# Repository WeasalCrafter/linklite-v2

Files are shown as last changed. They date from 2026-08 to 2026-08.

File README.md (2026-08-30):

<!-- PROJECT LOGO -->
<br />
<div align="center">
  <a href="https://github.com/weasalcrafter/linklite-v2">
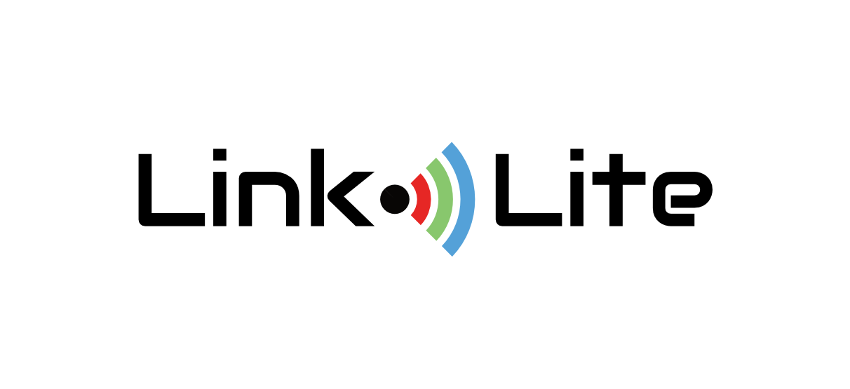
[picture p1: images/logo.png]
    
  </a>

  <h3 align="center">LinkLite v2</h3>

  <p align="center">
    A modular ESP32-C6 based room light that syncs brightness via ESP-NOW
    <br />
    <a href="https://www.loganfick.com/projects/linklite-v2">See my post on my Website</a><!--
    &middot;
    <a href="#">Project video on Youtube</a>-->
  </p>
</div>

<!-- TABLE OF CONTENTS -->
<details opeb>
  <summary>Table of Contents</summary>
  <ol>
    <li>
      <a href="#files">File Structure</a>
    <li><a href="#contact">Contact</a></li>
    <li><a href="#acknowledgments">Acknowledgments</a></li>
    <li><a href="#license">License</a></li>
  </ol>
</details>

<!-- ABOUT THE PROJECT -->
## About The Project

My dorm room lights are terrible in college, so I decided to make my own. LinkLite is the idea of a modular lighting system that lives locally and not in the cloud while allowing for wireless control and syncing. 

This is the second version of LinkLite, completely redesigned. This time with a custom PCB and much increased brightness.

### Built With

These are the major libraries I used in the programming in the project:

* RotaryEncoder
* Preferences
* ESP-NOW

<!-- CONTACT -->
## Files

The PCB project files can be found under ```kicad/linklite_v2```

```
linklite-v2
├── data
├── kicad
│   └── linklite_v2
├── linklite-bar
├── linklite-controller
├── temperature_logger
├── README.md
├── CLAUDE.md
└── LICENSE.txt
```

The arduino sketches for the ```linklite-bar```, ```linklite-controller```, and ```temperature_logger``` can be found under their respective folders, and my data collected can be found in the ```data``` folder along with the MATLAB script for plot generation.

<!-- CONTACT -->
## Contact

Logan Fick -  loganfickcontact@gmail.com

Project Link: [https://github.com/weasalcrafter/linklite-v2](https://github.com/weasalcrafter/linklite-v2)

Website: [https://loganfick.com/](https://loganfick.com/)

<!-- ACKNOWLEDGMENTS -->
## Acknowledgments
These are the tools I used for this project for designing the schematic, PCB layout, and programming.

* [Claude Code](https://www.claude.ai)
* [KiCad 10.0](https://www.kicad.org/)
* [Digikey Tools](https://www.digikey.com/en/resources/online-conversion-calculators)
* [MATLAB](https://www.mathworks.com/products/matlab.html)

## License

This project is licensed under the MIT License - see the [LICENSE](LICENSE.txt) file for details.

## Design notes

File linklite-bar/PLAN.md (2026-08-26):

# linklite-bar — Firmware Plan

Target: **ESP32-C6-MINI-1**, FQBN `esp32:esp32:esp32c6`. This is the authoritative brightness
node — see `CLAUDE.md` at the repo root for hardware pinout, the sync philosophy, and
conventions. This document is the detailed design for the `linklite-bar` sketch; the
accompanying `linklite-bar.ino` is a skeleton that implements the settled parts and stubs the
open ones with `// TODO(plan §n)` markers back into this file.

## 1. Responsibilities

The bar is the **stateful** half of the system (see CLAUDE.md "Sync model"). It:

1. Owns the authoritative brightness value for itself, and converges that value with peer bars.
2. Drives the LED array via LEDC PWM with a gamma-corrected curve.
3. Accepts brightness deltas and toggle events from controllers over ESP-NOW.
4. Answers late-joining bars' state queries so they converge instead of resetting the group.
5. Persists last brightness across power cycles.

Controllers never hold state — they only emit intent (`CLAUDE.md` §Sync model). Any logic that
looks like "wait for the controller to tell me the absolute level" is wrong; the bar decides.

## 2. Brightness domain

- Internal representation: **`uint8_t percent`, 0–100**, clamped on every mutation. Percent (not
  raw duty) is what gets stored in NVS, sent as `MSG_STATE`, and reasoned about in logic — it's
  radio- and hardware-independent.
- Conversion to PWM duty happens **only** at the output stage (§4), via a gamma LUT.
- One encoder detent from the controller = **±2 percent** (`STEP_SIZE_PERCENT`, shared constant
  with `linklite-controller`). Chosen so a full 0→100 sweep is ~50 detents — adjust after bench
  testing feels right; it's the one "magic number" both sketches must agree on today since there's
  no shared header between sketches yet (see §9 Conventions & gotchas).

## 3. GPIO & peripherals

Per `CLAUDE.md`:

| Function | GPIO | Mode |
|---|---|---|
| User button 1 | 20 | `INPUT_PULLUP`, debounced |
| User button 2 | 21 | `INPUT_PULLUP`, debounced |
| User LED | 22 | `OUTPUT` |
| Main LEDs | 23 | LEDC PWM (drives MOSFET gate)  |

## 4. LED driver (LEDC)

- **API:** arduino-esp32 3.x's pin-based LEDC calls — `ledcAttach(LED_PIN, freq, resBits)` /
  `ledcWrite(LED_PIN, duty)` — not the old channel-number API.
- **Frequency:** 5 kHz. Well clear of flicker/audible range, comfortably inside what the AO3400A
  can switch cleanly.
- **Resolution:** 12-bit (0–4095) for smooth low-end dimming.
- **Gamma correction:** the MOSFET+LED array is a linear-duty light source; human perception is
  roughly a power curve. Map `percent` (0–100) → duty via a **precomputed 101-entry LUT**
  (`const uint16_t GAMMA_LUT[101] PROGMEM`), `duty = round(4095 * (percent/100)^2.2)`.
  **Do not call `pow()`/float math at runtime on every step** — the C6 is RISC-V with no hardware
  FPU, so `pow()` is a soft-float library call; fine once at table-generation time (or precomputed
  by a script and pasted in as constants), not fine in a hot path.
- **At 0%:** drive duty to exactly 0, not the LUT's rounded near-zero value, so "off" is really off.

## 5. Boot sequence

1. Init serial (debug only), GPIO modes, LEDC attach.
2. Load persisted `percent` from NVS (`Preferences`, namespace `"linklite"`); if absent, default
   to a safe **25%** rather than 0% or 100% (visible but not startling). Drive the LEDC output to
   this provisional value immediately — don't leave the bar dark while radio comes up.
3. Bring up Wi-Fi STA (no AP association) pinned to the fixed **`WIFI_CHANNEL`** (both sketches
   hardcode the same channel — ESP-NOW requires it, and an unassociated STA otherwise reuses
   whatever channel is cached in Wi-Fi NVS, which can silently drift between devices). Init
   ESP-NOW, register the broadcast peer (`FF:FF:FF:FF:FF:FF`) and the recv callback.
4. Broadcast `MSG_QUERY`. Wait up to **500 ms** for `MSG_STATE` replies.
   - Every reply received in the window goes through the same last-write-wins comparison as
     steady-state heartbeats (§7.3): whichever `(level, stateVersion)` has the highest version
     wins, including possibly this bar's own NVS-loaded state if no peer beats it. This replaced
     an earlier "first reply wins" rule, which could stomp a correct persisted state with a
     lagging peer's stale reply.
   - If none arrive: this bar *is* the group (first one up, or alone) — keep the NVS/default value.
5. Enter main loop.

## 6. Main loop

Cooperative, non-blocking — no `delay()` in `loop()`:

- Poll button 1 / button 2 with debounce (simple time-based debounce is enough; these aren't
  latency-critical like the encoder).
- Drain a small ring buffer of received ESP-NOW packets (the recv callback runs in the Wi-Fi task
  context — keep it to "copy packet into buffer," do the real handling in `loop()`).
- Apply pending deltas → update `percent` → clamp 0–100 → `ledcWrite` via gamma LUT → mark NVS
  "dirty."
- Rate-limited NVS persistence: only write after **2 s of quiescence** since the last change, not
  on every step. Flash write cycles are finite and a fast encoder spin can generate many deltas/sec.
- Update the user LED per the status table in §8.
- Broadcast a `MSG_STATE` heartbeat every `STATE_HEARTBEAT_MS` (~100 ms) — the primary bar-to-bar
  sync mechanism, not just rare-drift reconciliation (§7.3); affordable because a converged bar's
  `peerStateWins()` check on receipt is cheap when `(version, level)` already match.

## 7. Wire protocol (ESP-NOW)

One packed struct, identical in both sketches until they're pulled into a shared header:

```c
typedef enum : uint8_t {
  MSG_DELTA  = 0x01,  // relative brightness step, from a controller (or another bar, unused today)
  MSG_TOGGLE = 0x02,  // on/off toggle, from a controller
  MSG_QUERY  = 0x03,  // "what's the current level?" — sent by a bar on boot
  MSG_STATE  = 0x04,  // response to MSG_QUERY, or periodic heartbeat (see §7.3)
} MsgType;

typedef struct __attribute__((packed)) {
  uint8_t  groupId;      // isolates separate physical installations sharing radio range; 0 = default
  uint8_t  msgType;      // MsgType
  uint8_t  senderType;   // 0 = bar, 1 = controller
  uint32_t seq;          // sender-local monotonic counter; debugging/ordering only, not for dedup
  int8_t   delta;        // MSG_DELTA/MSG_TOGGLE payload, in percent points
  uint8_t  level;        // MSG_STATE payload, absolute percent (0-100) — bootstrap/reconcile only
  uint32_t stateVersion; // MSG_STATE payload: Lamport-style logical clock, see §7.3
} LinkLitePacket; // 13 bytes
```

**Important distinction:** `level` in `MSG_STATE` is *not* a "set to X" control command — CLAUDE.md
is explicit that absolute set-points must never drive the control plane, because they let two
racing controllers stomp each other. `MSG_STATE` exists only to bootstrap a bar that has no local
state to converge from (§5 step 4) and, optionally, to nudge quiescent drift (§7.3). A bar must
never apply a received `MSG_STATE.level` while it has an active/recent delta stream in flight.

### 7.1 Delta application

On `MSG_DELTA`: `percent = clamp(percent + pkt.delta, 0, 100)`. On `MSG_TOGGLE`: if `percent > 0`,
remember it as `lastNonZeroPercent` and set `percent = 0`; if `percent == 0`, restore
`lastNonZeroPercent` (or the 25% default if none recorded yet).

### 7.2 No relay/rebroadcast in v1

Bars do **not** rebroadcast deltas they receive. ESP-NOW broadcast is single-hop and, for the
target install size (a handful of bars in one room, well within radio range of every controller
and each other), every bar hears every controller directly — a mesh relay adds storm-prevention
complexity (loop detection, TTLs, dedup) for no benefit at this scale. If a future install needs
bars spread across a range no single controller can reach, revisit this — it's a deliberate scope
cut, not an oversight.

### 7.3 Drift correction — last-write-wins via logical clock, implemented

Missed broadcasts (radio interference, a bar briefly out of range) cause silent drift between bars
since delta application isn't acknowledged — previously the only recovery was manually cranking
every bar to a rail (0% or 100%) so the independent-clamping property (§11) forced convergence.

**Design:** each bar keeps `brightnessVersion: uint32_t`, a Lamport-style logical clock (not
wall-clock time) tied 1:1 to its own `percent` mutations:

- **Local-origin mutation** (this bar applied a delta/toggle it received, or a local button press) →
  `version = version + 1`. This bar just created a new fact.
- **Remote-origin mutation** (adopting a peer's state) → `version = peerVersion`, assigned outright,
  *not* incremented. This bar isn't creating a new fact, it's aligning to one that already exists.
  Incrementing here too would make two bars that just converged each think they're now newest,
  oscillating forever instead of settling — this distinction is the crux of the whole scheme.
- Deliberately **not** persisted to NVS. Every reboot starts at `version = 0`, so a restarted bar
  has no standing in `peerStateWins()` and must join the group's current state via the boot query
  (§5 step 4) rather than asserting whatever it last knew — a bar that remembered its version
  across reboots could out-rank a peer's genuinely current state after a power cycle (e.g. mid
  firmware update) and stomp the group with a stale level. `percent` is still persisted, but only
  as a display fallback for the solo/no-peers case, not as a claim on the group's state.

Each bar broadcasts `MSG_STATE` (now carrying `level` **and** `stateVersion`) every
`STATE_HEARTBEAT_MS` (15 s). On receiving *any* `MSG_STATE` — heartbeat or boot-query reply, same
code path — a bar compares:

- `peerVersion > localVersion` → adopt the peer's `(level, version)`.
- `peerVersion == localVersion` but `level` differs → deterministic tie-break on MAC address
  (larger wins), so the group can't oscillate. This only arises from a genuinely concurrent or
  partitioned write (e.g. a bar toggled locally while out of range, whose increment from a stale
  baseline happens to numerically match a peer's independently-advanced version) — under normal
  operation, every mutation is broadcast and applied identically everywhere, so all bars advance
  their version in lockstep and this branch essentially never fires.
- `peerVersion < localVersion` → ignore; the peer is behind and will catch up on its next heartbeat.

This **replaced** the originally-proposed "nudge one step toward the received value if quiescent"
design. A bar only diverges when it's already missed updates — i.e. it's already visibly wrong —
so snapping straight to the winning value is the more direct fix, and the logical-clock ordering
already gives the "don't override a bar mid-adjustment" property the nudge/quiescence heuristic was
reaching for: a bar applying its own deltas keeps incrementing its own version, so a stale peer
heartbeat can't be `>` it and can't win.

Bench-validated behavior to confirm: induce packet loss on one bar mid-session, confirm it
re-converges within one heartbeat interval once back in range, and confirm no oscillation between
two bars deliberately desynced to the same version with different levels.

## 8. User LED (GPIO22) status codes

| State | Pattern |
|---|---|
| Normal / converged | Solid on |
| Booting, waiting for `MSG_STATE` | Slow blink (2 Hz) until step 5  |
| Delta received (activity indicator) | Brief single flash (~30 ms) |
| Pairing / group-assign mode (§9) | Fast blink (5 Hz) |
| Fault (e.g. ESP-NOW init failed) | Triple-flash, repeating |

## 9. Buttons 1 & 2 — OPEN DECISION, proposed defaults

CLAUDE.md doesn't define these; per the project's own convention of flagging rather than silently
deciding (see its Wireless transport section), here's a proposal to confirm, not a final answer:

- **Button 1, short press:** local on/off toggle — same effect as a controller `MSG_TOGGLE`,
  applied locally and then broadcast so peers follow. Useful for a bar with no controller nearby.
- **Button 1, long press (~2 s):** identify — fast-blink the user LED and pulse the main LEDs
  briefly, useful for figuring out which physical bar you're touching during setup.
- **Button 2:** reserved for **group/pairing management** (`groupId` assignment) — mechanism TBD.
  The simplest version: long-press enters pairing mode (fast user-LED blink), during which the bar
  accepts a `groupId` broadcast from a designated "pairing controller" gesture (e.g. a long
  controller-button-press while in range). This needs a controller-side counterpart that doesn't
  exist yet — out of scope until `linklite-controller`'s button role is revisited past its current
  on/off-toggle default (see repo root `CLAUDE.md`).

The skeleton wires both buttons with debounce and stubs their handlers; button 1's short-press
toggle is implemented (it's simple and low-risk), everything else is `// TODO(plan §9)`.

## 10. Persistence (NVS via `Preferences`)

Namespace `"linklite"`, keys: `pct` (`uint8_t`, last brightness — display fallback only, not a
state claim) and `grp` (`uint8_t`, `groupId`, default 0). `brightnessVersion` is intentionally
**not** persisted (see §7.3) so every boot re-joins the group via query instead of asserting a
possibly-stale version. Write path is rate-limited per §6. No encryption/auth on the ESP-NOW link
in v1 — flag
per CLAUDE.md's "don't silently pick" spirit: this means anything in radio range can inject deltas.
Acceptable for a single-room consumer light; revisit if the threat model changes (`esp_now` supports
per-peer AES-CCM encryption if needed later).

## 11. Edge cases

- **Two controllers turning at once:** deltas are commutative by construction (§7.1) — no special
  handling needed, this is the whole point of the delta model.
- **Clamping at rails:** every node clamps independently to 0–100; since clamping is deterministic
  and the same function everywhere, nodes can't drift apart at the rails even without coordination.
- **Late join:** handled by boot-time `MSG_QUERY`/`MSG_STATE` (§5). A bar joining mid-session must
  not default to a guessed value if peers are present.
- **Solo bar (no peers, no controller):** boots to NVS value or 25% default; buttons still work
  locally.
- **NVS write during brownout/power loss:** rate-limiting (§6) minimizes the window; worst case is
  losing up to 2 s of the most recent change, not corruption (`Preferences` commits are atomic per
  key).

## 12. File layout

- `linklite-bar.ino` — `setup()`/`loop()`, wires everything below together.
- `config.h` — pin defs, `LinkLitePacket`/`MsgType`, `WIFI_CHANNEL`, `STEP_SIZE_PERCENT`,
  `GAMMA_LUT`, timing constants. Kept as a header (not split .cpp/.h per module) since the sketch
  is still small; revisit if it grows past a few hundred lines per file.

## 13. Bench test plan (before calling this done)

1. Single bar, no controller: boots to default, buttons work, NVS persists across power cycle.
2. Single bar + single controller: rotate CW/CCW, confirm smooth gamma-correct dimming; push
   button toggles; confirm `STEP_SIZE_PERCENT` feels right, tune if not.
3. Two bars, one controller: both converge to the same brightness on every delta; power-cycle one
   bar mid-session and confirm it re-queries and converges instead of resetting.
4. Two bars, two controllers, simultaneous opposite turns: confirm net delta lands correctly with
   no fighting/flicker.
5. Induce packet loss (walk a bar out of range briefly): confirm behavior is "graceful drift," not
   a crash or LEDC glitch; use this to validate (or invalidate) §7.3 before implementing it.

## 14. Explicit open items (don't silently resolve — confirm first)

- §7.3 Drift-reconciliation heartbeat — implemented (last-write-wins via logical clock); not yet
  bench-validated against induced packet loss. `STATE_HEARTBEAT_MS` (~100 ms) chosen to make the
  heartbeat the primary sync path rather than a rare-case backstop; `RX_QUEUE_LEN` (linklite-bar.ino)
  was widened alongside it since the queue is shared with real controller commands.
- §9 Button roles — button 1 short-press implemented as proposed; everything else pending.
- §9 groupId assignment/pairing mechanism — no controller-side counterpart exists yet.
- `STEP_SIZE_PERCENT` (2%/detent) and the 25% power-on default — reasonable starting guesses, tune
  after bench testing.
- No ESP-NOW encryption — acceptable for now, flagged for revisit.

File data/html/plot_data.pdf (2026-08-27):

# Table of Contents

# --- Load Data ---

file = 'linklite_data_4.csv';
data = readmatrix(file); | % 20x9 numeric matrix
hdr = readcell(file, 'Range', '1:1'); | % header row (cell array of
strings)
brightness = 1; | % (%)
scaled_duty = 3; | % (%)
measured_duty = 4; | % (%)
total_current = 5; | % mA
power_consumption = 6; % W
voltage_drop = 7; | % V
voltage_rail = 8; | % V
led_current = 9; | % mA

efficiency = ((data(:,led_current) * 28) .* data(:,voltage_rail)) ./ ... ((data(:,total_current) - 72) * 15); % (%)

buck_output = efficiency .* data(:,total_current) .* 15 ./ data(:,voltage_rail)

buck_output =

1.0e+03 *

NaN
NaN
0.0818
0.1194
0.1494
0.1675
0.1875
0.2215
0.2546
0.2960
0.3427
0.3925
0.4502
0.5219
0.5954
0.6698
1.1706

1.3122
1.4525
1.5970
1.7941

# graphing data

figure;

sgtitle("Linklite Power Metrics", 'fontsize', 44);

subplot(2,2,1);
plot(data(:,brightness), data(:,power_consumption), '-c', 'LineWidth', 2.5, 'MarkerSize', 10, 'Color', 'g');
title("Power Consumption (W) vs. Brightness (%)", 'FontSize', 28)
xlim([0 100]);
grid on;

subplot(2,2,2);
plot(data(:,brightness), data(:,led_current), 'LineWidth', 2.5, 'Color', 'r'); xlim([0 100]);
ylim([0 60]);
title("LED Forward Current (V) vs. Bightness (%)", 'FontSize', 28);
grid on;

subplot(2,2,3);
plot(data(:,brightness), efficiency, 'LineWidth', 2.5, 'Color', 'y'); xlim([0 100]);
ylim([0 1]);
title("Calculated Buck Efficiency (%) vs. Brightness (%)", 'FontSize', 28); grid on;

subplot(2,2,4);
plot(data(:,brightness), buck_output, 'LineWidth', 2.5, 'color', 'c'); xlim([0 100]);
ylim([0 2000]);
title("Buck Output (mA) vs. Brightness (%)", 'FontSize', 28);
grid on;

for k = 1:4
subplot(2,2,k);
% ... your plot, title, labels ... set(gca, 'FontSize', 20);
end

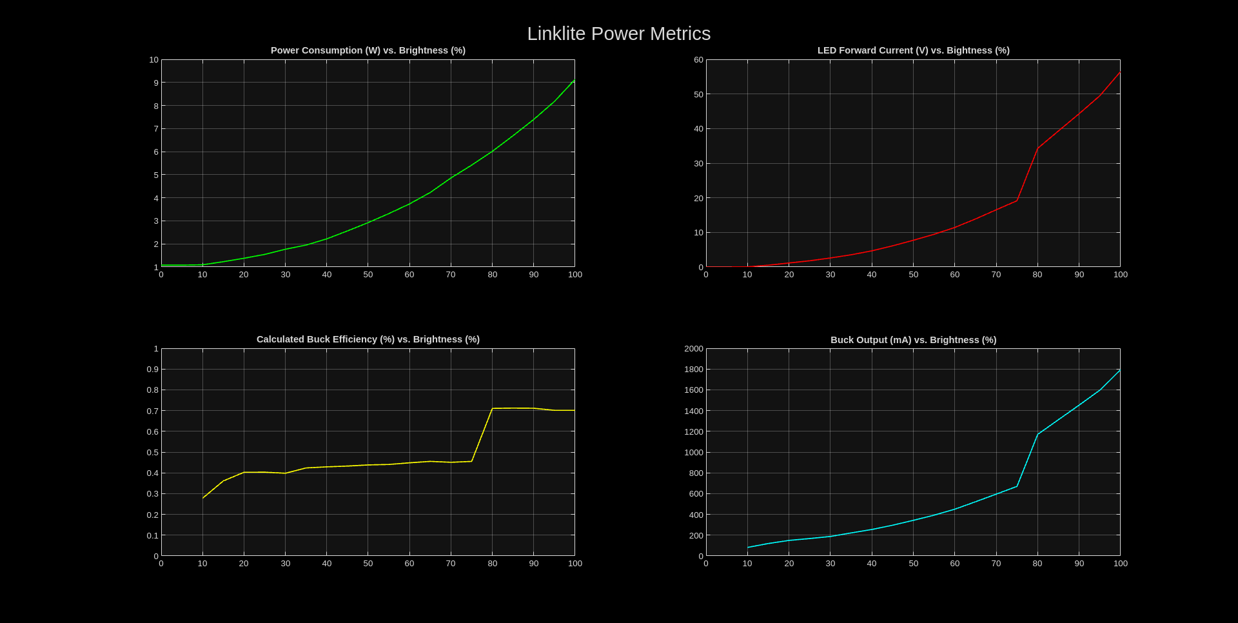
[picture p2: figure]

# --- Load and Graph Experimental Data ---

figure

hold on

temp_file = 'files/data_006.csv';
temp_data = readmatrix(temp_file); plot(temp_data(:,1),temp_data(:,2),'LineWidth',2);

temp_file = 'files/data_010.csv';
temp_data = readmatrix(temp_file); plot(temp_data(:,1),temp_data(:,2),'LineWidth',2);

temp_file = 'files/data_008.csv';
temp_data = readmatrix(temp_file); plot(temp_data(:,1),temp_data(:,2),'LineWidth',2);

temp_file = 'files/data_009.csv';
temp_data = readmatrix(temp_file); plot(temp_data(:,1),temp_data(:,2),'LineWidth',2);

temp_data_1 = readmatrix('files/data_011.csv'); temp_data_2 = readmatrix('files/data_012.csv');
temp_data_3 = readmatrix('files/data_013.csv');

% shortest row count across the three
n = min([size(temp_data_1,1), size(temp_data_2,1), size(temp_data_3,1)]);

% trim each to n rows
d1 = temp_data_1(1:n, :);
d2 = temp_data_2(1:n, :);

d3 = temp_data_3(1:n, :);

averaged_temp = (d1(:,1) + d2(:,1) + d3(:,1)) ./ 3; plot(averaged_temp, d1(:,2));

temp_file = 'files/data_014.csv';
temp_data = readmatrix(temp_file); plot(temp_data(:,1),temp_data(:,2),'LineWidth',2);

hold off
grid on

set(gca, 'FontSize', 24);

xticks(0:300:1800);
xlim([0 1800]);

yticks(20:5:70);
ylim([20 70]);

xlabel("Time (s)", FontSize=28);
ylabel("Temperature (C)", FontSize=28);
title("LED-Side PCB Temperature (Celsius) vs. Time (Seconds)",FontSize=38);

legend( ...
'Single 90% (014)', ...
'Single 80% (006)', ...
'Single 80% (010)', ...
'Double 80% (008)', ...
'Triple 80% (009)', ...
'Single 60% (011/012/013)', ... 'fontsize',28, ...
'Location','Southeast' ...
);

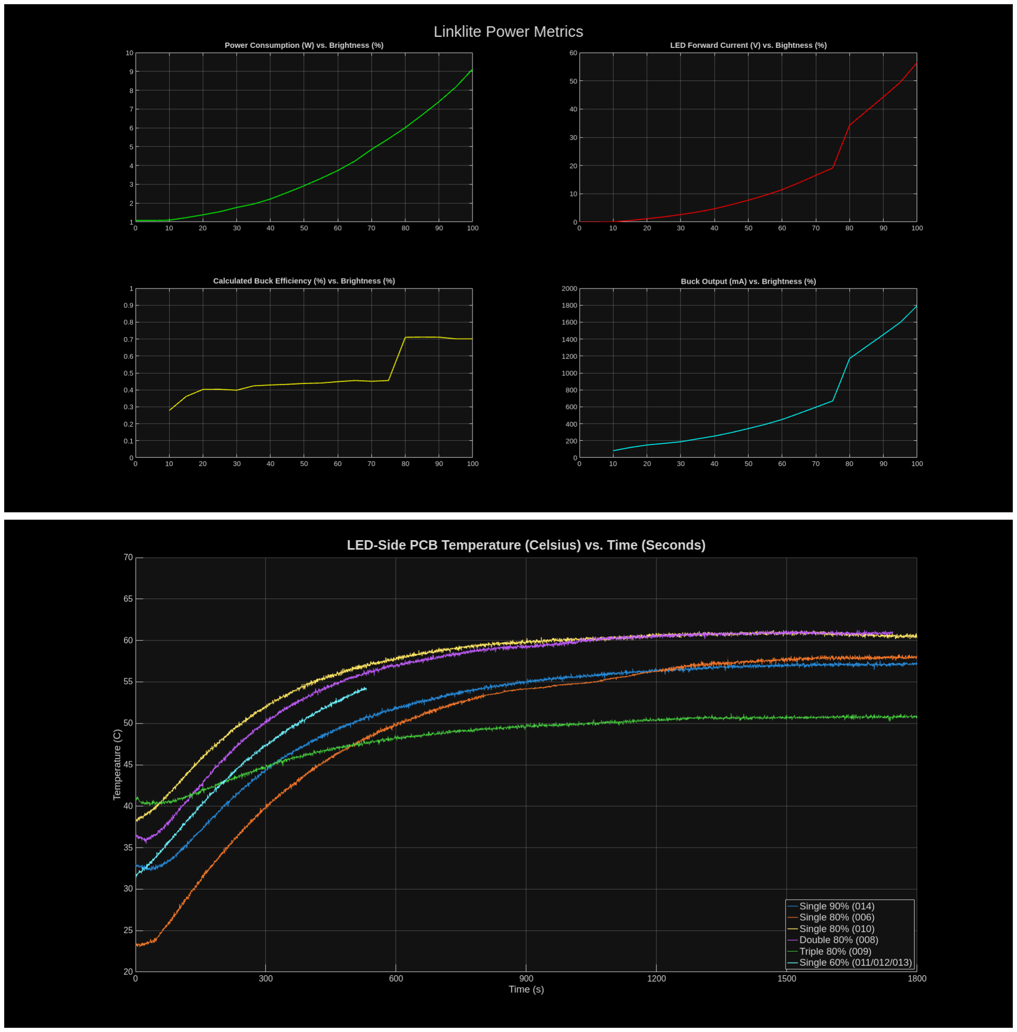
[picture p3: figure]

Published with MATLAB® R2025b

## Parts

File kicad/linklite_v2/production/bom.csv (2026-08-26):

Designator | Footprint | Quantity | Value | LCSC Part #
C1, C4, C5 | 0603 | 3 | 0.1uF
C10 | CAP-SMD_BD6.3-L6.6-W6.6-LS7.3-FD_JVS25V100M6X4 | 1 | JVS25V100M6X4 | C51953404
C13, C6 | 0805 | 2 | 22uF
C15, C16 | 0805 | 2 | 10uF 25V
C17 | 0603 | 1 | 0.1uF 25V
C2 | 0603 | 1 | 22uF
C3, C9 | 0603 | 2 | 1uF
C8 | 0805 | 1 | 0.1uF 25V
D3 | D_MiniMELF | 1 | BZV55B10
D4 | SMC_L7.1-W6.2-LS8.1-FD | 1 | SMCJ15A-13-F | C135138
F3, F4 | F2920 | 2 | JK-SMD300L-24V | C841188
J2 | PinHeader_1x03_P2.54mm_Horizontal | 1 | Conn_01x03_Pin
J3 | PinHeader_1x11_P2.54mm_Horizontal | 1 | Conn_01x11_Pin
L1 | IND-SMD_L7.3-W6.6 | 1 | MHCI06030-3R3M-R8 | C108294
LED1, LED10, LED11, LED12, LED13, LED14, LED15, LED16, LED17, LED18, LED19, LED2, LED21, LED22, LED23, LED25, LED26, LED27, LED29, LED3, LED30, LED31, LED4, LED5, LED6, LED7, LED8, LED9 | LED-SMD_L3.5-W2.8-FD-2835_WHITE | 28 | JTLMS3 | C34162565
LED33 | LED0603-RD_RED | 1 | PD LED RED | C94743
LED35 | LED0603-RD_RED | 1 | USR LED BLUE | C481916
LED36 | LED0603-RD_RED | 1 | PWR LED GREEN | C84267
Q2 | SOT-23-3_L2.9-W1.6-P1.90-LS2.8-BR | 1 | G7P03L | C840062
Q3 | SOT-23 | 1 | AO3400A
R1, R17, R19, R20, R21, R22, R23, R24, R25, R26, R27, R28, R29, R30, R31, R32, R33, R34, R36, R37, R38, R40, R41, R42, R44, R45, R46, R6 | 0603 | 28 | 5.6 | C325756
R10, R16, R2, R4, R48, R49, R7, R8, R9 | 0603 | 9 | 10K
R11 | 0603 | 1 | 33.2K
R12 | 0603 | 1 | 160
R13 | 0603 | 1 | 1K
R14, R15 | 0603 | 2 | 5.1K
R18, R5 | 0603 | 2 | 100K
R3 | 0603 | 1 | 220
R50 | 0603 | 1 | 180
R51 | 0603 | 1 | 130
SW3 | SW-SMD_4P-L3.5-W3.0-P1.50-LS4.7 | 1 | RESET | C51927445
SW4 | SW-SMD_4P-L3.5-W3.0-P1.50-LS4.7 | 1 | BOOT | C51927445
SW5, SW6 | SW-SMD_4P-L3.5-W3.0-P1.50-LS4.7 | 2 | USR 1 | C51927445
U2 | ESP32-C6-MINI-1 | 1 | ESP32-C6-MINI-1 | C5736265
U3 | SOT-666 | 1 | USBLC6-2P6
U5 | SOT-23-6 | 1 | CH221K
U6 | CONN-SMD_2060-452 | 1 | PWR OUT | C2765055
U7 | SOT-23-6_L2.9-W1.6-P0.95-LS2.8-BR | 1 | TPS563201DDCR | C116592
U8 | CONN-SMD_2060-452 | 1 | PWR IN | C2765055
USBC1 | USB-C_SMD-TYPE-C-31-M-12_1 | 1 | TYPE-C-31-M-12 | C165948

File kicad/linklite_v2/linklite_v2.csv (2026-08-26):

Designator | Comment | Footprint | LCSC Part
USBC1 | TYPE-C-31-M-12 | EasyEDA2KiCad:USB-C_SMD-TYPE-C-31-M-12_1 | C165948
U8 | PWR IN | EasyEDA2KiCad:CONN-SMD_2060-452 | C2765055
U7 | TPS563201DDCR | EasyEDA2KiCad:SOT-23-6_L2.9-W1.6-P0.95-LS2.8-BR | C116592
U6 | PWR OUT | EasyEDA2KiCad:CONN-SMD_2060-452 | C2765055
U5 | CH221K | Package_TO_SOT_SMD:SOT-23-6
U3 | USBLC6-2P6 | Package_TO_SOT_SMD:SOT-666
U2 | ESP32-C6-MINI-1 | RF_Module:ESP32-C6-MINI-1
SW5,SW6 | USR 1 | EasyEDA2KiCad:SW-SMD_4P-L3.5-W3.0-P1.50-LS4.7 | C51927445
SW4 | BOOT | EasyEDA2KiCad:SW-SMD_4P-L3.5-W3.0-P1.50-LS4.7 | C51927445
SW3 | RESET | EasyEDA2KiCad:SW-SMD_4P-L3.5-W3.0-P1.50-LS4.7 | C51927445
R14,R15 | 5.1K | Resistor_SMD:R_0603_1608Metric
R13 | 1K | Resistor_SMD:R_0603_1608Metric
R12,R50,R51 | 75 | Resistor_SMD:R_0603_1608Metric
R11 | 33.2K | Resistor_SMD:R_0603_1608Metric
R5,R18 | 100K | Resistor_SMD:R_0603_1608Metric
R4,R7,R8,R9,R10,R16,R48,R49 | 10K | Resistor_SMD:R_0603_1608Metric
R3 | 220 | Resistor_SMD:R_0603_1608Metric
R2 | 10k | Resistor_SMD:R_0603_1608Metric
R1,R6,R17,R19,R20,R21,R22,R23,R24,R25,R26,R27,R28,R29,R30,R31,R32,R33,R34,R36,R37,R38,R40,R41,R42,R44,R45,R46 | 5.8 | Resistor_SMD:R_0603_1608Metric
Q3 | AO3400A | Package_TO_SOT_SMD:SOT-23
Q2 | G7P03L | EasyEDA2KiCad:SOT-23-3_L2.9-W1.6-P1.90-LS2.8-BR | C840062
LED36 | PWR LED GREEN | EasyEDA2KiCad:LED0603-RD_RED | C94743
LED35 | USR LED BLUE | EasyEDA2KiCad:LED0603-RD_RED | C94743
LED33 | PD LED RED | EasyEDA2KiCad:LED0603-RD_RED | C94743
LED1,LED2,LED3,LED4,LED5,LED6,LED7,LED8,LED9,LED10,LED11,LED12,LED13,LED14,LED15,LED16,LED17,LED18,LED19,LED21,LED22,LED23,LED25,LED26,LED27,LED29,LED30,LED31 | JTLMS3 | EasyEDA2KiCad:LED-SMD_L3.5-W2.8-FD-2835_WHITE | C34162565
L1 | MHCI06030-3R3M-R8 | EasyEDA2KiCad:IND-SMD_L7.3-W6.6 | C108294
J3 | Conn_01x11_Pin | Connector_PinHeader_2.54mm:PinHeader_1x11_P2.54mm_Horizontal
J2 | Conn_01x03_Pin | Connector_PinHeader_2.54mm:PinHeader_1x03_P2.54mm_Horizontal
H1,H2,H3,H4 | MountingHole | MountingHole:MountingHole_3.2mm_M3_Pad_TopBottom
F3,F4 | JK-SMD300L-24V | EasyEDA2KiCad:F2920 | C841188
D4 | SMCJ15A-13-F | EasyEDA2KiCad:SMC_L7.1-W6.2-LS8.1-FD | C135138
D3 | BZV55B10 | Diode_SMD:D_MiniMELF
C17 | 0.1uF 25V | Capacitor_SMD:C_0603_1608Metric
C15,C16 | 10uF 25V | Capacitor_SMD:C_0805_2012Metric
C10 | JVS25V100M6X4 | EasyEDA2KiCad:CAP-SMD_BD6.3-L6.6-W6.6-LS7.3-FD_JVS25V100M6X4 | C51953404
C8 | 0.1uF 25V | Capacitor_SMD:C_0805_2012Metric
C6,C13 | 22uF | Capacitor_SMD:C_0805_2012Metric
C3,C9 | 1uF | Capacitor_SMD:C_0603_1608Metric
C2 | 22uF | Capacitor_SMD:C_0603_1608Metric
C1,C4,C5 | 0.1uF | Capacitor_SMD:C_0603_1608Metric

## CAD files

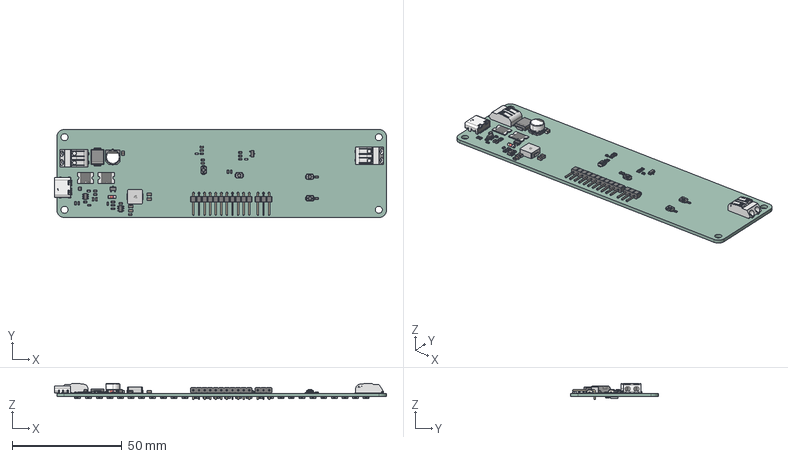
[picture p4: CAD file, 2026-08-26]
kicad/linklite_v2/.step
151.1 x 40.0 x 7.50 mm
C_0603_1608Metric x 7
C_0805_2012Metric x 5
R_0603_1608Metric x 47
KEY-SMD_2P-L3.0-W2.5-H1.6-LS4.0 x 4
PinHeader_1x03_P254mm_Horizontal
SOT-23-6_L2.9-W1.6-H1.5-LS2.8-P0.95
SOT_666
PinHeader_1x11_P254mm_Horizontal
LED0603-RD_RED x 3
IND-SMD_L7.1-W6.6-H2.8
D_MiniMELF_Standard
F2920-1 x 2
SOT-23-3L_L2.9-W1.6-H1.1-LS2.8-P0.95
SOT-23-6
CONN-SMD_2060-452 x 2
SOT-23
CAP-SMD_BD6.3-L6.6-W6.6-LS7.3-FD_JVS25V100M6X4
USB-C_SMD-TYPE-C-31-M-12
SMC_L7.1-W6.2-LS8.1-FD
LED-SMD_L3.5-W2.8-FD-2835_WHITE x 28
linklite_v2_PCB

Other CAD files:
kicad/linklite_v2/linklite-v2.step

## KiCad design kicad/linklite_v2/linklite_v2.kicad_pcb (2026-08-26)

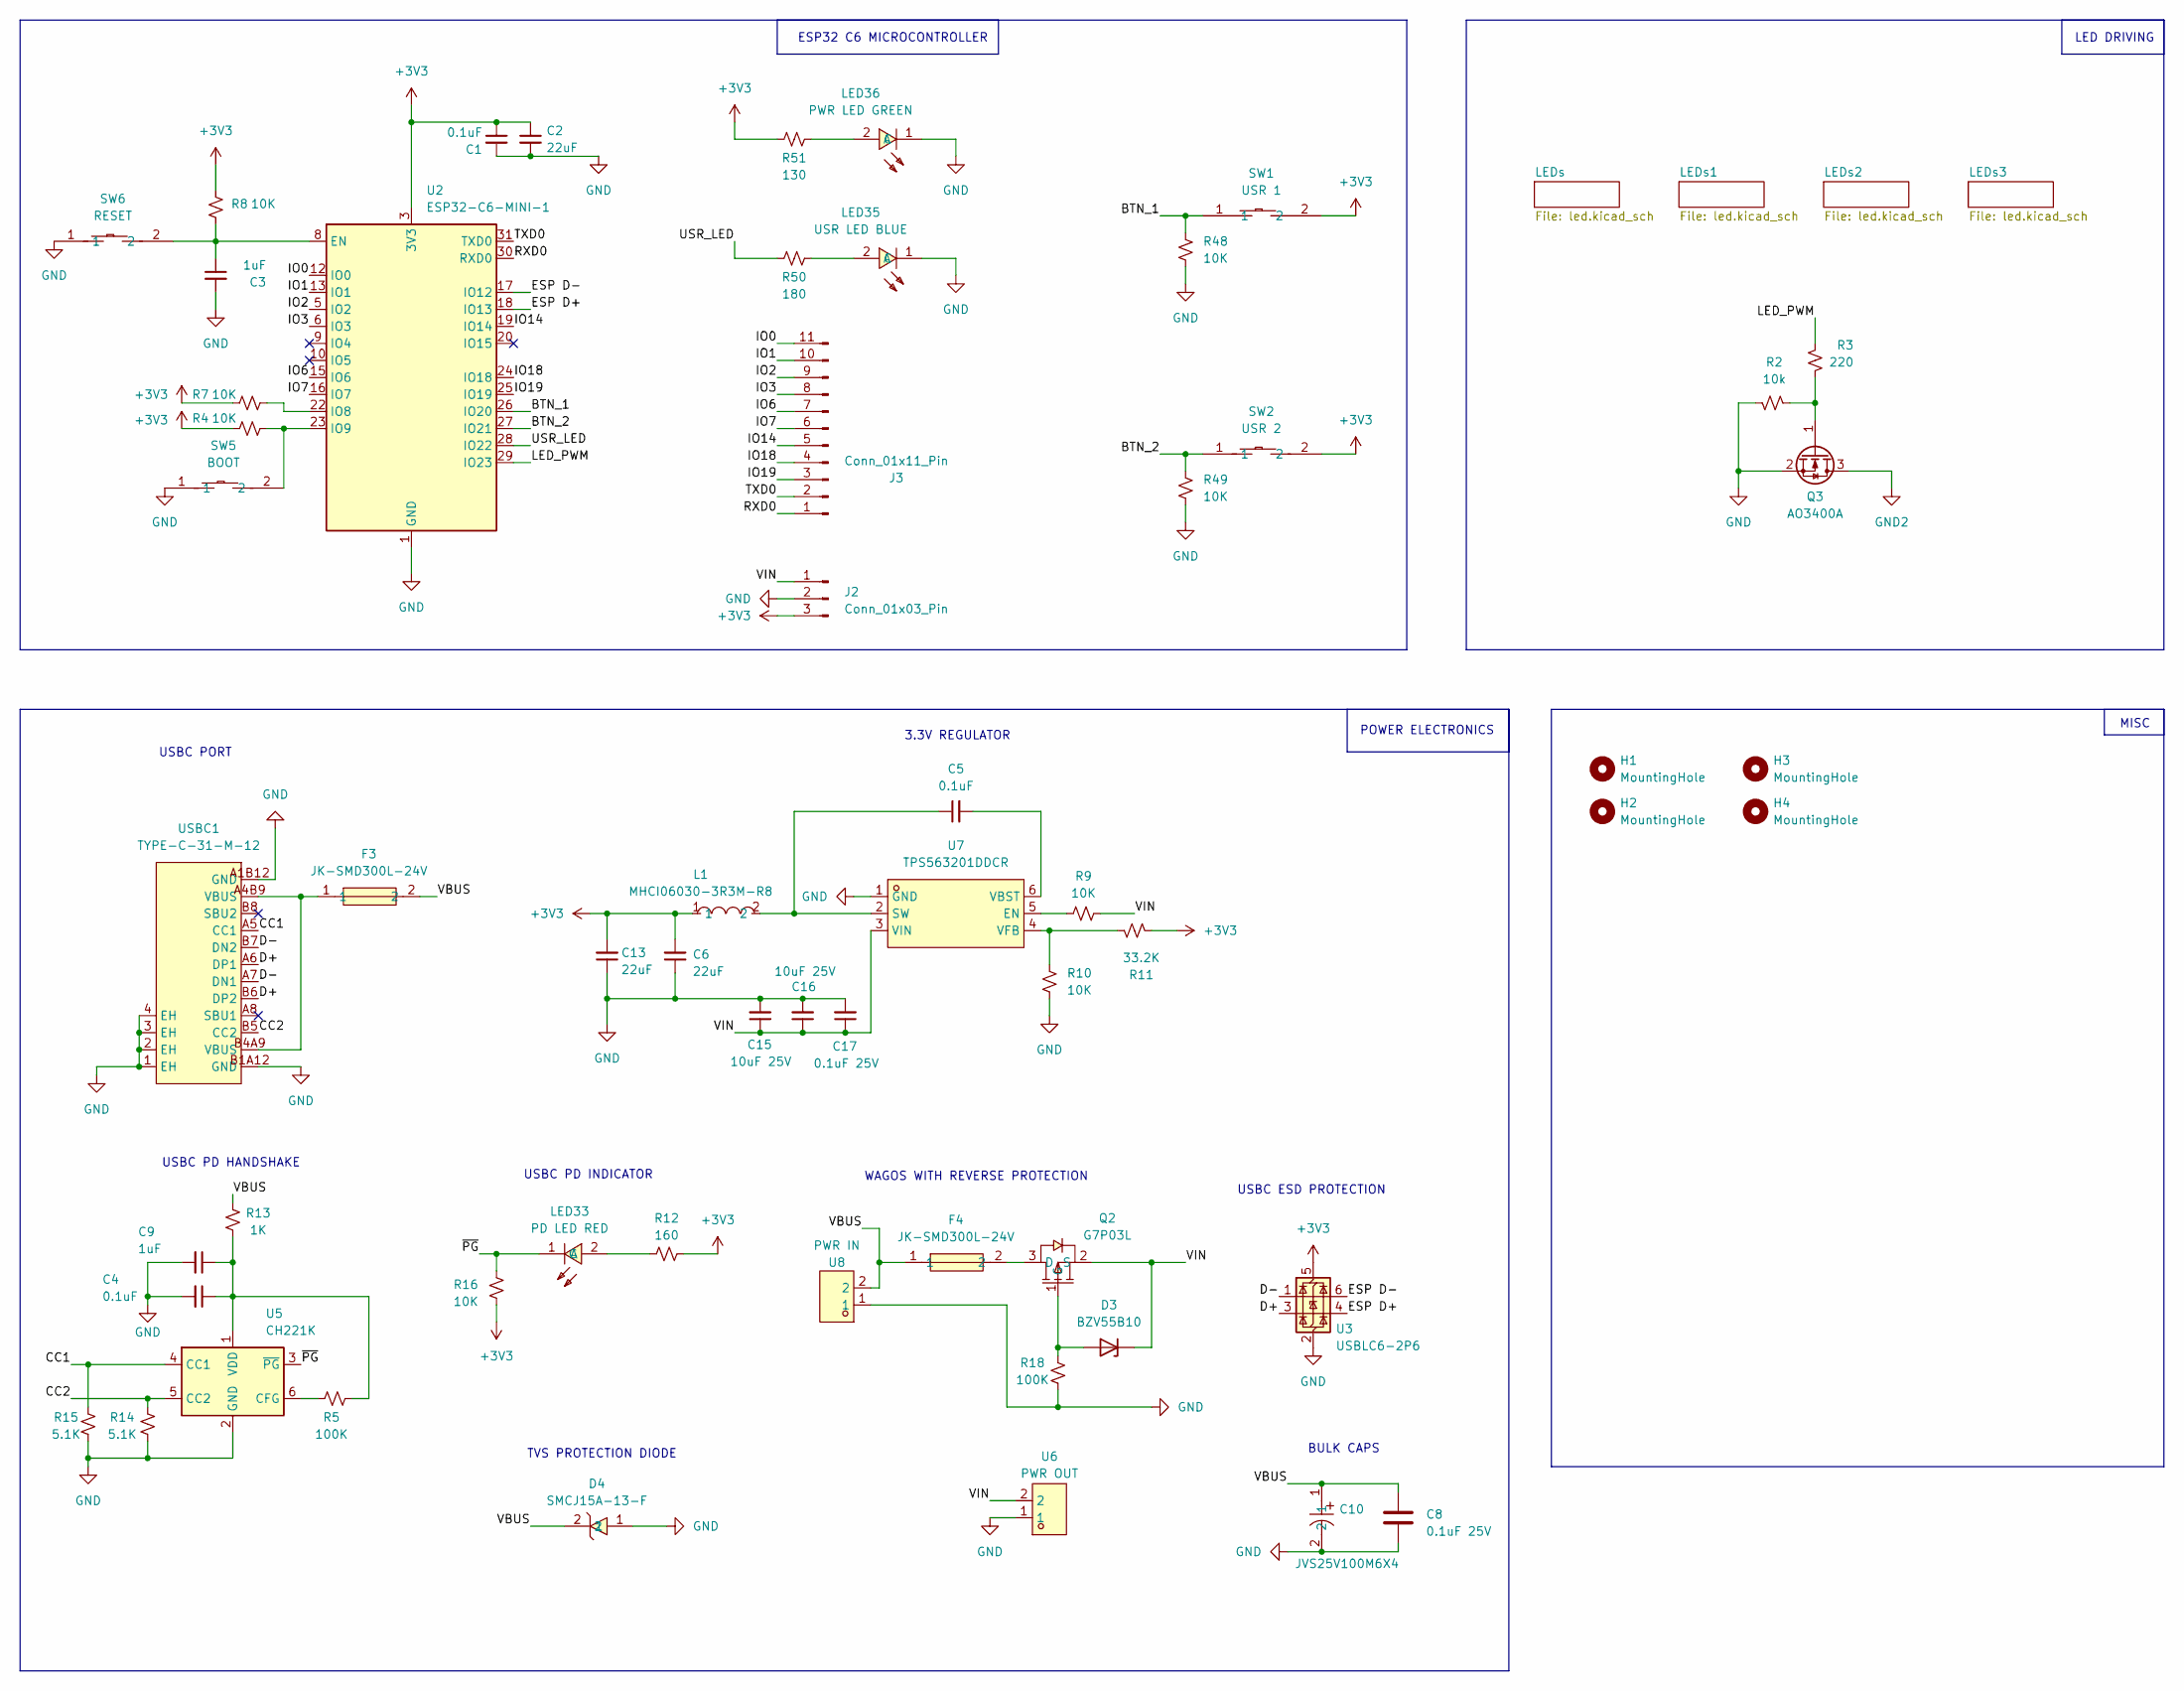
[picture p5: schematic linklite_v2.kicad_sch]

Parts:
C1, C4, C5: 0.1uF; C_0603_1608Metric
C2: 22uF; C_0603_1608Metric
C3, C9: 1uF; C_0603_1608Metric
C6, C13: 22uF; C_0805_2012Metric
C8: 0.1uF 25V; C_0805_2012Metric
C10: JVS25V100M6X4; CAP-SMD_BD6.3-L6.6-W6.6-LS7.3-FD_JVS25V100M6X4; MPN JVS25V100M6X4; LCSC Part C51953404
C15, C16: 10uF 25V; C_0805_2012Metric
C17: 0.1uF 25V; C_0603_1608Metric
D3: BZV55B10; D_MiniMELF
D4: SMCJ15A-13-F; SMC_L7.1-W6.2-LS8.1-FD; MPN SMCJ15A-13-F; LCSC Part C135138
F3, F4: JK-SMD300L-24V; F2920; MPN JK-SMD300L-24V; LCSC Part C841188
H1, H2, H3, H4: MountingHole; MountingHole_3.2mm_M3_Pad_TopBottom
J2: Conn_01x03_Pin; PinHeader_1x03_P2.54mm_Horizontal
J3: Conn_01x11_Pin; PinHeader_1x11_P2.54mm_Horizontal
L1: MHCI06030-3R3M-R8; IND-SMD_L7.3-W6.6; MPN MHCI06030-3R3M-R8; LCSC Part C108294
LED33: PD LED RED; LED0603-RD_RED; MPN BL-HUB36G-AV-TRB; LCSC Part C94743
LED35: USR LED BLUE; LED0603-RD_RED; MPN BL-HUB36G-AV-TRB; LCSC Part C481916
LED36: PWR LED GREEN; LED0603-RD_RED; MPN BL-HUB36G-AV-TRB; LCSC Part C84267
Q2: G7P03L; SOT-23-3_L2.9-W1.6-P1.90-LS2.8-BR; MPN G7P03L; LCSC Part C840062
Q3: AO3400A; SOT-23
R2: 10k; R_0603_1608Metric
R3: 220; R_0603_1608Metric
R4, R7, R8, R9, R10, R16, R48, R49: 10K; R_0603_1608Metric
R5, R18: 100K; R_0603_1608Metric
R11: 33.2K; R_0603_1608Metric
R12: 160; R_0603_1608Metric
R13: 1K; R_0603_1608Metric
R14, R15: 5.1K; R_0603_1608Metric
R50: 180; R_0603_1608Metric
R51: 130; R_0603_1608Metric
SW1: USR 1; KEY-SMD_B3U-1000PM; MPN B3U-1000P; LCSC Part C231329
SW2: USR 2; KEY-SMD_B3U-1000PM; MPN B3U-1000P; LCSC Part C231329
SW5: BOOT; KEY-SMD_B3U-1000PM; MPN B3U-1000P; LCSC Part C231329
SW6: RESET; KEY-SMD_B3U-1000PM; MPN B3U-1000P; LCSC Part C231329
U2: ESP32-C6-MINI-1; LCSC Part C5736265
U3: USBLC6-2P6; SOT-666
U5: CH221K; SOT-23-6
U6: PWR OUT; CONN-SMD_2060-452; MPN 2060-452/998-404; LCSC Part C2765055
U7: TPS563201DDCR; SOT-23-6_L2.9-W1.6-P0.95-LS2.8-BR; MPN TPS563201DDCR; LCSC Part C116592
U8: PWR IN; CONN-SMD_2060-452; MPN 2060-452/998-404; LCSC Part C2765055
USBC1: TYPE-C-31-M-12; USB-C_SMD-TYPE-C-31-M-12_1; LCSC Part C165948

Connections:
+3V3: C1.1, C2.1, C6.2, C13.2, J2.3, L1.1, R4.1, R7.1, R8.1, R11.2, R12.2, R16.1, R51.1, SW1.2, SW2.2, U2.3 (3V3), U3.5 (VBUS); also elsewhere on the board
/BTN_1: R48.1, SW1.1, U2.26 (IO20)
/BTN_2: R49.1, SW2.1, U2.27 (IO21)
/CC1: R15.2, U5.4 (CC1), USBC1.A5 (CC1)
/CC2: R14.2, U5.5 (CC2), USBC1.B5 (CC2)
/D+: U3.3 (I/O2), USBC1.A6 (DP1), USBC1.B6 (DP2)
/D-: U3.1 (I/O1), USBC1.A7 (DN1), USBC1.B7 (DN2)
/ESP D+: U2.18 (IO13), U3.4 (I/O2)
/ESP D-: U2.17 (IO12), U3.6 (I/O1)
/IO0: J3.11, U2.12 (IO0)
/IO1: J3.10, U2.13 (IO1)
/IO2: J3.9, U2.5 (IO2)
/IO3: J3.8, U2.6 (IO3)
/IO6: J3.7, U2.15 (IO6)
/IO7: J3.6, U2.16 (IO7)
/IO14: J3.5, U2.19 (IO14)
/IO18: J3.4, U2.24 (IO18)
/IO19: J3.3, U2.25 (IO19)
/LED_PWM: R3.1, U2.29 (IO23)
/RXD0: J3.1, U2.30 (RXD0)
/TXD0: J3.2, U2.31 (TXD0)
/USR_LED: R50.1, U2.28 (IO22)
/VBUS: C8.1, C10.1, D4.2, F3.2, F4.1, R13.2, U8.2
/VIN: C15.1, C16.1, C17.1, D3.1 (K), J2.1, Q2.2 (S), R9.2, U6.2, U7.3 (VIN)
/~PG: LED33.1 (C), R16.2, U5.3 (~PG)
GND: C1.2, C2.2, C3.2, C4.2, C6.1, C8.2, C9.2, C10.2, C13.1, C15.2, C16.2, C17.2, D4.1, J2.2, LED35.1 (C), LED36.1 (C), Q3.2 (S), R2.1, R10.1, R14.1, R15.1, R18.1, R48.2, R49.2, SW5.1, SW6.1, U2.1 (GND), U2.2 (GND), U2.11 (GND), U2.14 (GND), U2.36 (GND), U2.37 (GND), U2.38 (GND), U2.39 (GND), U2.40 (GND), U2.41 (GND), U2.42 (GND), U2.43 (GND), U2.44 (GND), U2.45 (GND), U2.46 (GND), U2.47 (GND), U2.48 (GND), U2.49 (GND), U2.50 (GND), U2.51 (GND), U2.52 (GND), U2.53 (GND), U3.2 (GND), U5.2 (GND), U6.1, U7.1 (GND), U8.1, USBC1.1 (EH), USBC1.2 (EH), USBC1.3 (EH), USBC1.4 (EH), USBC1.A1B12 (GND), USBC1.B1A12 (GND)
GND2: Q3.3 (D); also elsewhere on the board
unnamed: D3.2 (A), Q2.1 (G), R18.2
unnamed: F3.1, USBC1.A4B9 (VBUS), USBC1.B4A9 (VBUS)
unnamed: LED33.2 (A), R12.1
unnamed: LED35.2 (A), R50.2
unnamed: LED36.2 (A), R51.2
unnamed: F4.2, Q2.3 (D)
unnamed: Q3.1 (G), R2.2, R3.2
unnamed: C3.1, R8.2, SW6.2, U2.8 (EN)
unnamed: R7.2, U2.22 (IO8)
unnamed: R4.2, SW5.2, U2.23 (IO9)
unnamed: R5.1, U5.6 (CFG)
unnamed: C4.1, C9.1, R5.2, R13.1, U5.1 (VDD)
unnamed: R9.1, U7.5 (EN)
unnamed: C5.1, L1.2, U7.2 (SW)
unnamed: C5.2, U7.6 (VBST)
unnamed: R10.2, R11.1, U7.4 (VFB)

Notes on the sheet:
USBC ESD PROTECTION
ESP32 C6 MICROCONTROLLER
BULK CAPS
USBC PD INDICATOR
USBC PORT
USBC PD HANDSHAKE
WAGOS WITH REVERSE PROTECTION
MISC
3.3V REGULATOR
LED DRIVING
TVS PROTECTION DIODE
POWER ELECTRONICS

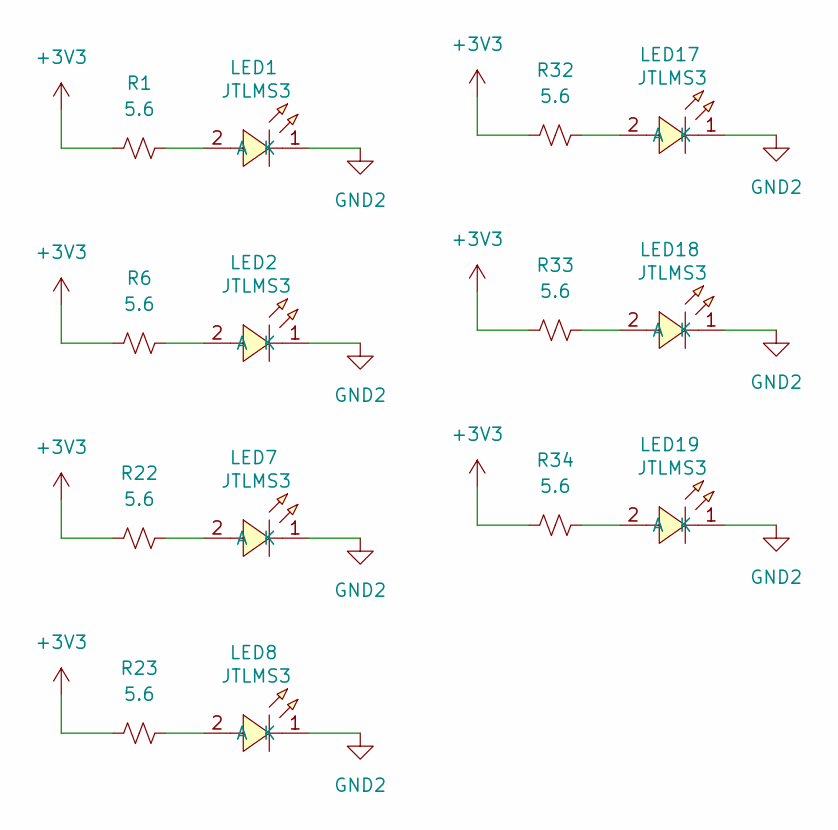
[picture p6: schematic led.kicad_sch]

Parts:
LED1, LED2, LED7, LED8, LED17, LED18, LED19: JTLMS3; LED-SMD_L3.5-W2.8-FD-2835_WHITE; MPN GW JTLMS3.GM-G4G8-XX57-1-60-R33; LCSC Part C34162565
R1, R6, R22, R23, R32, R33, R34: 5.6; R_0603_1608Metric; LCSC Part C325756

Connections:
+3V3: R1.2, R6.2, R22.2, R23.2, R32.2, R33.2, R34.2; also elsewhere on the board
GND2: LED1.1 (K), LED2.1 (K), LED7.1 (K), LED8.1 (K), LED17.1 (K), LED18.1 (K), LED19.1 (K); also elsewhere on the board
unnamed: LED1.2 (A), R1.1
unnamed: LED2.2 (A), R6.1
unnamed: LED7.2 (A), R22.1
unnamed: LED8.2 (A), R23.1
unnamed: LED17.2 (A), R32.1
unnamed: LED18.2 (A), R33.1
unnamed: LED19.2 (A), R34.1

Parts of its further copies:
LED3, LED4, LED5, LED6, LED9, LED10, LED11, LED12, LED13, LED14, LED15, LED16, LED21, LED22, LED23, LED25, LED26, LED27, LED29, LED30, LED31: JTLMS3; LED-SMD_L3.5-W2.8-FD-2835_WHITE; MPN GW JTLMS3.GM-G4G8-XX57-1-60-R33; LCSC Part C34162565
R17, R19, R20, R21, R24, R25, R26, R27, R28, R29, R30, R31, R36, R37, R38, R40, R41, R42, R44, R45, R46: 5.6; R_0603_1608Metric; LCSC Part C325756

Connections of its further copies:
+3V3: R17.2, R19.2, R20.2, R21.2, R24.2, R25.2, R26.2, R27.2, R28.2, R29.2, R30.2, R31.2, R36.2, R37.2, R38.2, R40.2, R41.2, R42.2, R44.2, R45.2, R46.2; also elsewhere on the board
GND2: LED3.1 (K), LED4.1 (K), LED5.1 (K), LED6.1 (K), LED9.1 (K), LED10.1 (K), LED11.1 (K), LED12.1 (K), LED13.1 (K), LED14.1 (K), LED15.1 (K), LED16.1 (K), LED21.1 (K), LED22.1 (K), LED23.1 (K), LED25.1 (K), LED26.1 (K), LED27.1 (K), LED29.1 (K), LED30.1 (K), LED31.1 (K); also elsewhere on the board
unnamed: LED3.2 (A), R17.1
unnamed: LED4.2 (A), R19.1
unnamed: LED5.2 (A), R20.1
unnamed: LED6.2 (A), R21.1
unnamed: LED9.2 (A), R24.1
unnamed: LED10.2 (A), R25.1
unnamed: LED11.2 (A), R26.1
unnamed: LED12.2 (A), R27.1
unnamed: LED13.2 (A), R28.1
unnamed: LED14.2 (A), R29.1
unnamed: LED15.2 (A), R30.1
unnamed: LED16.2 (A), R31.1
unnamed: LED21.2 (A), R36.1
unnamed: LED22.2 (A), R37.1
unnamed: LED23.2 (A), R38.1
unnamed: LED25.2 (A), R40.1
unnamed: LED26.2 (A), R41.1
unnamed: LED27.2 (A), R42.1
unnamed: LED29.2 (A), R44.1
unnamed: LED30.2 (A), R45.1
unnamed: LED31.2 (A), R46.1

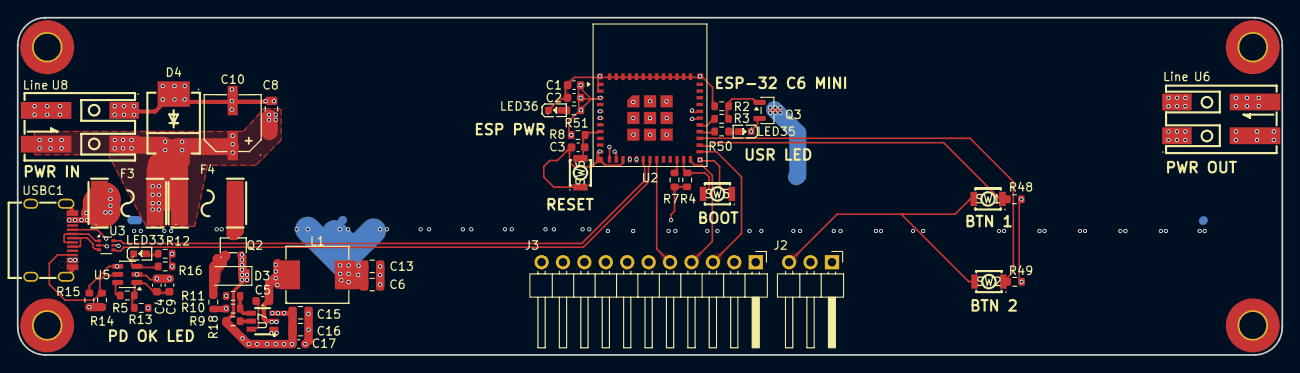
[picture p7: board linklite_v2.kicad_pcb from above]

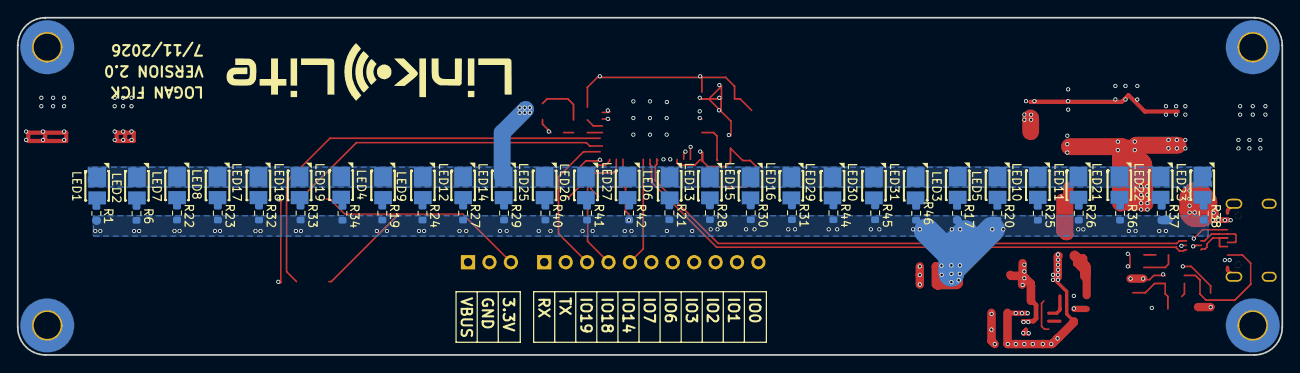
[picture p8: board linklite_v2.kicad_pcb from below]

Board: 4 copper layers, 150.0 x 40.0 mm, 115 parts (56 on the bottom side), 71 nets.

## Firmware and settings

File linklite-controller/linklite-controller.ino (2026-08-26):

// linklite-controller.ino
// ESP32-C3 remote: EC11 rotary encoder + push button, ESP-NOW to the bars.
// Stateless emitter of intent only (CLAUDE.md "Sync model") — never tracks or assumes a
// brightness level, just emits relative deltas and a toggle event, then goes back to sleep.
//
// Lifecycle: light sleep (GPIO wake source) -> wake on encoder/button edge -> short awake
// session polling further motion + debouncing the button -> emit ESP-NOW packet(s) -> idle
// timeout -> back to light sleep. Light sleep retains RAM/CPU state, so plain (non-RTC) statics
// survive across sleep cycles and resume is fast.

#include <esp_now.h>
#include <esp_wifi.h>
#include <WiFi.h>
#include <esp_sleep.h>
#include <driver/gpio.h>
#include <RotaryEncoder.h>
#include "config.h"

static const uint8_t BROADCAST_MAC[6] = {0xFF, 0xFF, 0xFF, 0xFF, 0xFF, 0xFF};

uint32_t txSeq = 0;

// Encoder decode/debounce lives in the RotaryEncoder library (Gray-code latch state machine) —
// see setup() for construction. Polled from runAwakeSession()'s loop rather than driven by an
// A/B interrupt: RotaryEncoder::tick() isn't IRAM-resident, and calling it from an IRAM ISR at
// the moment flash cache happens to be disabled (e.g. during esp_wifi_set_channel(), which
// runAwakeSession() calls on every wake) faults hard enough to wedge the chip until physical
// reset. The awake session already polls every 5ms for button debounce, so folding the encoder
// into that same loop costs nothing and avoids the ISR path entirely.
RotaryEncoder *encoder = nullptr;

void onEspNowSent(const wifi_tx_info_t *info, esp_now_send_status_t status) {
	if (status != ESP_NOW_SEND_SUCCESS) {
		Serial.println("ESP-NOW send failed"); // surfaces the exact failure this bug report needs
	}
}

void sendPacket(MsgType type, int8_t delta, uint8_t level) {
	LinkLitePacket pkt = {};
	pkt.groupId = DEFAULT_GROUP_ID;
	pkt.msgType = type;
	pkt.senderType = SENDER_CONTROLLER;
	pkt.seq = txSeq++;
	pkt.delta = delta;
	pkt.level = level;
	esp_now_send(BROADCAST_MAC, (uint8_t *)&pkt, sizeof(pkt));
}

void configureWakeSources() {
	gpio_wakeup_enable((gpio_num_t)PIN_ENC_A, GPIO_INTR_LOW_LEVEL);
	gpio_wakeup_enable((gpio_num_t)PIN_ENC_B, GPIO_INTR_LOW_LEVEL);
	gpio_wakeup_enable((gpio_num_t)PIN_ENC_BTN, GPIO_INTR_LOW_LEVEL);
	esp_sleep_enable_gpio_wakeup();
}

void enterLightSleepUntilWake() {
	esp_light_sleep_start();
}

// Runs from wake until IDLE_TIMEOUT_MS of no further encoder/button activity, then returns so
// the caller can go back to sleep. Batches encoder motion into as few ESP-NOW sends as possible.
void runAwakeSession() {
	// The C3's Wi-Fi/RF state isn't guaranteed to come back exactly as it was after
	// esp_light_sleep_start() — in practice the channel can end up unset/wrong on wake, which
	// silently breaks ESP-NOW TX until the whole device (and its Wi-Fi driver) is reset. Since a
	// full reset is exactly what "fixes" this in the field, reassert the channel every wake
	// rather than trusting it survived sleep.
	Serial.println("Waking up!");

	esp_wifi_set_channel(WIFI_CHANNEL, WIFI_SECOND_CHAN_NONE);

	encoder->tick();
	long lastPosition = encoder->getPosition();

	bool btnDebounced = digitalRead(PIN_ENC_BTN);
	bool btnLastRaw = btnDebounced;
	uint32_t btnLastChangeMs = millis();

	uint32_t lastActivityMs = millis();
	uint32_t debugLedOffMs = 0; // 0 = LED currently off; nonzero = pending turn-off deadline

	while (millis() - lastActivityMs < IDLE_TIMEOUT_MS) {
		encoder->tick();
		long position = encoder->getPosition();
		long steps = position - lastPosition;
		lastPosition = position;

		if (steps != 0) {
			int32_t percentDelta = (int32_t)steps * STEP_SIZE_PERCENT;
			if (percentDelta > 127) percentDelta = 127;
			if (percentDelta < -127) percentDelta = -127;
			sendPacket(MSG_DELTA, (int8_t)percentDelta, 0);
			lastActivityMs = millis();

			if (DEBUG_ENCODER_LED) {
				digitalWrite(PIN_DEBUG_LED, LOW); // active-low: on
				debugLedOffMs = lastActivityMs + DEBUG_LED_FLASH_MS;
			}
		}

		if (DEBUG_ENCODER_LED && debugLedOffMs != 0 && millis() >= debugLedOffMs) {
			digitalWrite(PIN_DEBUG_LED, HIGH); // active-low: off
			debugLedOffMs = 0;
		}

		bool raw = digitalRead(PIN_ENC_BTN);
		uint32_t now = millis();
		if (raw != btnLastRaw) {
			btnLastRaw = raw;
			btnLastChangeMs = now;
		}
		if (now - btnLastChangeMs > BUTTON_DEBOUNCE_MS && btnDebounced != raw) {
			btnDebounced = raw;
			if (btnDebounced == HIGH) { // released (active-low button, so HIGH = released)
				sendPacket(MSG_TOGGLE, 0, 0); // on/off toggle, per project decision
				lastActivityMs = now;
			}
		}

		delay(5);
	}

	if (DEBUG_ENCODER_LED) digitalWrite(PIN_DEBUG_LED, HIGH); // off before sleeping, in case a flash was still pending
}

void setup() {
	Serial.begin(115200);

	// RotaryEncoder's 2-pin constructor configures PIN_ENC_A/B as INPUT_PULLUP itself. FOUR3
	// matches our wiring: both pins idle HIGH (via pull-up) at rest, so external position only
	// latches at that all-HIGH state — see LatchMode comments in RotaryEncoder.h.
	encoder = new RotaryEncoder(PIN_ENC_A, PIN_ENC_B, RotaryEncoder::LatchMode::FOUR3);

	pinMode(PIN_ENC_BTN, INPUT_PULLUP);

	if (DEBUG_ENCODER_LED) {
		pinMode(PIN_DEBUG_LED, OUTPUT);
		digitalWrite(PIN_DEBUG_LED, HIGH); // active-low: start off
	}

	WiFi.mode(WIFI_STA);
	WiFi.disconnect();
	WiFi.setTxPower(WIFI_POWER_8_5dBm); // ~8.5 dBm — reduced from the ~20 dBm default for close-range
	                                     // bench testing; avoids overdriving a receiver inches away and
	                                     // is a reasonable steady-state level for single-room operation
	// Wi-Fi's own power-save state machine (modem sleep, DTIM-driven wake, etc.) is meant to
	// coordinate with an AP connection we don't have here, and fighting it with our own explicit
	// esp_light_sleep_start() calls is a known source of the radio not coming back cleanly after
	// sleep. We already own all the power saving via light sleep — keep Wi-Fi's PS state machine
	// out of it entirely so the radio is always in a known-good state whenever we're awake.
	esp_wifi_set_ps(WIFI_PS_NONE);
	// Fixed channel: an unassociated STA otherwise reuses whatever channel is cached in Wi-Fi
	// NVS, which can silently drift out of sync with the bars (must match linklite-bar/config.h).
	esp_wifi_set_channel(WIFI_CHANNEL, WIFI_SECOND_CHAN_NONE);

	if (esp_now_init() != ESP_OK) {
		Serial.println("ESP-NOW init failed");
		// No user-facing indicator on this board (no status LED per CLAUDE.md's controller
		// pinout) - nothing further to do here; retry logic is out of scope for this skeleton.
	} else {
		Serial.println("ESP-NOW init success!");
		esp_now_register_send_cb(onEspNowSent);
		esp_now_peer_info_t peer = {};
		memcpy(peer.peer_addr, BROADCAST_MAC, 6);
		peer.channel = WIFI_CHANNEL;
		peer.encrypt = false; // matches linklite-bar; no ESP-NOW encryption in v1
		esp_now_add_peer(&peer);
	}

	configureWakeSources();
}

void loop() {
	enterLightSleepUntilWake();

	esp_sleep_wakeup_cause_t cause = esp_sleep_get_wakeup_cause();
	if (cause != ESP_SLEEP_WAKEUP_GPIO) return; // spurious wake; loop back to sleep immediately

	runAwakeSession();
}

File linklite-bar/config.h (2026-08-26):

// linklite-bar/config.h
// Pin map, wire protocol, and tuning constants. See PLAN.md for the design behind these.
//
// NOTE: LinkLitePacket / MsgType / WIFI_CHANNEL / STEP_SIZE_PERCENT must stay identical to the
// copies in ../linklite-controller/linklite-controller.ino until the two sketches share a header
// (PLAN.md §9 / §12 — there's no shared-library setup yet, so this is a manually-kept invariant).

#pragma once

#include <Arduino.h>

// ---- GPIO map (CLAUDE.md "Light bar" table) --------------------------------------------------
#define PIN_BUTTON_1  20
#define PIN_BUTTON_2  21
#define PIN_USER_LED  22 // 22 for c6 and 8 for c3
#define PIN_MAIN_LEDS 23 // 23 for c6 and 0 for c3

// ---- LEDC (PWM) config (PLAN.md §4) -----------------------------------------------------------
#define LEDC_FREQ_HZ     25000
#define LEDC_RES_BITS    8
#define LEDC_MAX_DUTY    ((1 << LEDC_RES_BITS) - 1)  // max raw duty for the configured resolution

// GAMMA_LUT below is precomputed at a fixed 12-bit domain (0..4095) regardless of LEDC_RES_BITS —
// see the LUT comment. Rescale its output to LEDC_MAX_DUTY at runtime so changing LEDC_RES_BITS
// (or LEDC_FREQ_HZ, which constrains max achievable resolution) can't desync percent from duty.
#define GAMMA_LUT_MAX_DUTY 4095

// Hard ceiling on output duty cycle, as a percentage of LEDC_MAX_DUTY. Lets max LED current be
// capped in firmware (thermal/driver limits) without touching the gamma curve or brightness math.
#define LEDC_MAX_DUTY_PERCENT 100

// ---- Brightness domain (PLAN.md §2) -----------------------------------------------------------
#define BRIGHTNESS_MIN_PCT   0
#define BRIGHTNESS_MAX_PCT   80
#define BRIGHTNESS_DEFAULT_PCT 30   // used only if NVS has no stored value and no peers respond
#define STEP_SIZE_PERCENT    5      // must match linklite-controller's per-detent step

// ---- Radio (PLAN.md §5 step 3, §10) -----------------------------------------------------------
#define WIFI_CHANNEL     1          // must match linklite-controller; ESP-NOW requires same channel
#define DEFAULT_GROUP_ID 0

// ---- Timing (PLAN.md §5, §6) ------------------------------------------------------------------
#define BOOT_QUERY_TIMEOUT_MS   500
#define NVS_WRITE_QUIESCE_MS    2000
#define BUTTON_DEBOUNCE_MS      30
#define BUTTON_LONG_PRESS_MS    2000
#define ACTIVITY_FLASH_MS       30

// How often each bar broadcasts its own (level, stateVersion) as a last-write-wins heartbeat.
// Deliberately fast: this is the primary bar-to-bar sync mechanism, not just a rare-drift
// safety net, so lag is bounded to ~this interval instead of just "eventually." Frequency is
// affordable because peerStateWins() (linklite-bar.ino) short-circuits to false the instant
// (version, level) already match, so a converged bar pays only a cheap comparison per received
// heartbeat, not a setBrightness()/LEDC/NVS touch — see RX_QUEUE_LEN in linklite-bar.ino for the
// one real cost of raising this (shared RX buffer headroom against real controller commands).
#define STATE_HEARTBEAT_MS      100

// ---- Wire protocol (PLAN.md §7) ---------------------------------------------------------------
enum MsgType : uint8_t {
	MSG_DELTA  = 0x01,  // relative brightness step, from a controller
	MSG_TOGGLE = 0x02,  // on/off toggle, from a controller
	MSG_QUERY  = 0x03,  // "what's the current level?" — sent by a bar on boot
	MSG_STATE  = 0x04,  // response to MSG_QUERY, or periodic drift-reconciliation heartbeat
};

enum SenderType : uint8_t {
	SENDER_BAR        = 0,
	SENDER_CONTROLLER = 1,
};

typedef struct __attribute__((packed)) {
	uint8_t  groupId;
	uint8_t  msgType;     // MsgType
	uint8_t  senderType;  // SenderType
	uint32_t seq;
	int8_t   delta;       // MSG_DELTA / MSG_TOGGLE payload, percent points
	uint8_t  level;       // MSG_STATE payload, absolute percent 0-100
	uint32_t stateVersion; // MSG_STATE payload: Lamport-style logical clock for last-write-wins
	                       // reconciliation between bars (PLAN.md §7.3). NOT wall-clock time, and
	                       // NOT the same thing as `seq` above (seq is per-sender and resets to 0
	                       // every boot, so it can't be compared across bars or survive a reboot).
} LinkLitePacket;         // 13 bytes, __packed__ so both sketches agree on wire layout

// ---- Gamma LUT (PLAN.md §4) --------------------------------------------------------------------
// duty = round(4095 * (percent/100)^2.2), percent = 0..100. Precomputed — do NOT call pow() at
// runtime, the C6 (RISC-V) has no hardware FPU and pow() is a soft-float library call.
// TODO(plan §4): this table is a placeholder derived from the formula above; re-derive/tune once
// LEDs are on the bench and perceived linearity can actually be judged by eye.
extern const uint16_t GAMMA_LUT[101];

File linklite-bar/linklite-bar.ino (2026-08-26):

// linklite-bar.ino
// Authoritative brightness node — see PLAN.md for the full design this implements.
// Settled pieces (GPIO/LEDC, NVS, ESP-NOW init/send/recv, delta/toggle application, boot query)
// are implemented. Open design points are marked `// TODO(plan §n)` and left unimplemented —
// see PLAN.md §14 for the list.

#include <esp_now.h>
#include <esp_wifi.h>
#include <WiFi.h>
#include <Preferences.h>
#include "config.h"

const uint16_t GAMMA_LUT[101] = {
	0, 0, 1, 2, 3, 6, 8, 12, 16, 20,
	26, 32, 39, 46, 54, 63, 73, 83, 94, 106,
	119, 132, 146, 161, 177, 194, 211, 230, 249, 269,
	290, 311, 334, 357, 382, 407, 433, 460, 487, 516,
	545, 576, 607, 640, 673, 707, 742, 778, 815, 852,
	891, 931, 972, 1013, 1056, 1099, 1144, 1189, 1235, 1283,
	1331, 1380, 1431, 1482, 1534, 1587, 1642, 1697, 1753, 1810,
	1868, 1928, 1988, 2049, 2111, 2175, 2239, 2304, 2371, 2438,
	2506, 2576, 2646, 2718, 2790, 2864, 2939, 3014, 3091, 3169,
	3248, 3328, 3409, 3491, 3574, 3658, 3743, 3830, 3917, 4005,
	4095,
};

static const uint8_t BROADCAST_MAC[6] = {0xFF, 0xFF, 0xFF, 0xFF, 0xFF, 0xFF};

Preferences prefs;

volatile uint8_t brightnessPct = BRIGHTNESS_DEFAULT_PCT;
uint8_t lastNonZeroPct = BRIGHTNESS_DEFAULT_PCT;
uint8_t groupId = DEFAULT_GROUP_ID;
uint32_t txSeq = 0;

// Last-write-wins drift reconciliation (PLAN.md §7.3). Lamport-style logical clock, NOT wall-clock
// time: bumped by +1 on a local-origin mutation (this bar applied a delta/toggle itself — a new
// fact), or assigned outright to a peer's version when adopting its state (not a new fact, just
// aligning to one that already exists). Getting those two cases backwards — incrementing on
// adopt too — would make two bars that just converged each think they're now newest, oscillating
// forever instead of settling. See setBrightness() and peerStateWins().
//
// RAM-only, deliberately NOT persisted to NVS: every boot starts at 0 so this bar has zero standing
// in peerStateWins() until it hears otherwise. That's intentional — see the boot-query comment in
// setup(). A bar that remembered its last version across reboots could out-rank a peer's genuinely
// current state after being power-cycled mid-session (e.g. after a firmware update), stomping the
// group with a stale level instead of joining it.
uint32_t brightnessVersion = 0;
uint32_t lastHeartbeatMs = 0;
uint8_t selfMac[6];

// Rate-limited NVS persistence (PLAN.md §6)
bool nvsDirty = false;
uint32_t lastChangeMs = 0;

// User LED state machine (PLAN.md §8)
enum UserLedMode { LED_BOOT_WAIT, LED_NORMAL, LED_FLASH, LED_PAIRING, LED_FAULT };
UserLedMode userLedMode = LED_BOOT_WAIT;
uint32_t userLedFlashUntilMs = 0;

// Recv callback runs in the Wi-Fi task context — keep it to a copy into this small ring buffer,
// do real handling in loop() (PLAN.md §6). Sender MAC is carried alongside the packet (from
// esp_now_recv_info_t::src_addr, not the wire payload) for peerStateWins()'s tie-break.
// Widened from 8: this queue is shared by every incoming packet type, including real
// MSG_DELTA/MSG_TOGGLE from controllers, and STATE_HEARTBEAT_MS (config.h) is fast enough now
// that a burst of peer heartbeats could otherwise fill it right as a real command arrives — the
// recv callback drops silently on overflow, so headroom here matters more than it used to.
#define RX_QUEUE_LEN 16
struct RxEntry {
	LinkLitePacket pkt;
	uint8_t srcMac[6];
};
RxEntry rxQueue[RX_QUEUE_LEN];
volatile uint8_t rxHead = 0, rxTail = 0;

// Button debounce state (PLAN.md §9)
struct ButtonState {
	uint8_t pin;
	bool lastRaw;
	bool debounced;
	uint32_t lastChangeMs;
	uint32_t pressStartMs;
	bool longPressFired;
};
ButtonState button1 = {PIN_BUTTON_1, true, true, 0, 0, false};
ButtonState button2 = {PIN_BUTTON_2, true, true, 0, 0, false};

bool bootQueryPending = false;
uint32_t bootQueryStartMs = 0;

void setBrightness(uint8_t pct, uint32_t version);
void applyDelta(int8_t delta);
void applyToggle();
void sendPacket(MsgType type, int8_t delta, uint8_t level);
bool peerStateWins(uint32_t peerVersion, uint8_t peerLevel, const uint8_t *peerMac);
void onEspNowRecv(const esp_now_recv_info_t *info, const uint8_t *data, int len);
void handleRxQueue();
void handleButtons();
void updateUserLed();
void persistIfDirty();
void flashActivity();

void setup() {
	Serial.begin(115200);

	pinMode(PIN_BUTTON_1, INPUT_PULLUP);
	pinMode(PIN_BUTTON_2, INPUT_PULLUP);
	pinMode(PIN_USER_LED, OUTPUT);
	digitalWrite(PIN_USER_LED, LOW);

	ledcAttach(PIN_MAIN_LEDS, LEDC_FREQ_HZ, LEDC_RES_BITS);

	// Step 2 (PLAN.md §5): load persisted state, drive output immediately so the bar isn't dark
	// while radio comes up. `pct` is trusted only as a *display placeholder* here, not as this
	// bar's claim on the group's true state — it's shown immediately, then version 0 (below) makes
	// sure it's the first thing given up the moment a peer answers the boot query in setup(). If no
	// peer answers (solo bar, or first one up), nothing ever beats it and it quietly becomes the
	// group's starting value — which is correct, since in that case it's the only value that exists.
	//
	// `groupId`, by contrast, IS trusted outright and unconditionally: it's not a brightness claim
	// but this bar's own identity/broadcast-domain membership, and every packet's groupId is
	// checked against it before anything else runs (handleRxQueue()). There's no query/converge
	// step for it the way there is for brightness — whatever NVS says this bar's group is, is final
	// until a future pairing flow (PLAN.md §9, not implemented) explicitly changes it. Note this is
	// a filter, not authentication — ESP-NOW is unencrypted (PLAN.md §10), so it only isolates
	// installations from each other, it doesn't stop a bad actor in radio range from spoofing it.
	prefs.begin("linklite", false);
	uint8_t loadedPct = prefs.getUChar("pct", BRIGHTNESS_DEFAULT_PCT);
	groupId = prefs.getUChar("grp", DEFAULT_GROUP_ID);
	lastNonZeroPct = loadedPct > 0 ? loadedPct : BRIGHTNESS_DEFAULT_PCT;
	setBrightness(loadedPct, 0); // version 0: no standing until a peer says otherwise, see setup()'s boot query below
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

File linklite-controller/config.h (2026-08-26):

// linklite-controller/config.h
// Pin map, wire protocol, and tuning constants for the EC11 remote.
//
// NOTE: LinkLitePacket / MsgType / WIFI_CHANNEL / STEP_SIZE_PERCENT must stay identical to the
// copies in ../linklite-bar/config.h until the two sketches share a header — there's no
// shared-library setup yet, so this is a manually-kept invariant (see linklite-bar/PLAN.md §12).

#pragma once

#include <Arduino.h>

// ---- GPIO map (CLAUDE.md "Controller" table) --------------------------------------------------
// Flagged in CLAUDE.md as "not yet fixed" — these are usable as light-sleep GPIO wake sources on
// the C3 (any GPIO works for light sleep, unlike deep sleep's RTC-IO-only restriction), so they're
// kept as documented until there's a reason to move them.
#define PIN_ENC_A 20//2
#define PIN_ENC_B 21 //1
#define PIN_ENC_BTN 10  //3

// ---- Brightness domain (must match linklite-bar/config.h) --------------------------------------
#define STEP_SIZE_PERCENT 5  // percent points emitted per encoder detent

// ---- Radio (must match linklite-bar/config.h) ---------------------------------------------------
#define WIFI_CHANNEL 1
#define DEFAULT_GROUP_ID 0

// ---- Timing --------------------------------------------------------------------------------------
// Encoder debounce is handled by the RotaryEncoder library's Gray-code latch state machine
// (LatchMode::FOUR3) rather than a time-based gate — see linklite-controller.ino.
#define BUTTON_DEBOUNCE_MS 30
#define IDLE_TIMEOUT_MS 250  // no activity for this long -> back to light sleep

// ---- Debug -----------------------------------------------------------------------------------
// Onboard LED on the ESP32-C3 SuperMini dev board (GPIO8, active-low: LOW = on). Not present on
// the final controller PCB (CLAUDE.md's Controller table has no status LED), so this is bring-up
// only — flashes whenever the encoder registers motion, to distinguish "wake/decode never
// happened" from "it decoded fine but ESP-NOW comms to the bars is broken." Flip off before
// building for the real board.
static const bool DEBUG_ENCODER_LED = true;
#define PIN_DEBUG_LED 8
#define DEBUG_LED_FLASH_MS 40

// ---- Wire protocol (must match linklite-bar/config.h) --------------------------------------------
enum MsgType : uint8_t {
	MSG_DELTA = 0x01,
	MSG_TOGGLE = 0x02,
	MSG_QUERY = 0x03,
	MSG_STATE = 0x04,
};

enum SenderType : uint8_t {
	SENDER_BAR = 0,
	SENDER_CONTROLLER = 1,
};

typedef struct __attribute__((packed)) {
	uint8_t groupId;
	uint8_t msgType;
	uint8_t senderType;
	uint32_t seq;
	int8_t delta;
	uint8_t level;
	uint32_t stateVersion;  // bar-to-bar LWW reconciliation clock; the controller never sets this
	                        // (packets are zero-initialized), just carries the field for layout parity.
} LinkLitePacket;  // 13 bytes

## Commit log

2026-08-14 v1.0: baseline before LWW drift-reconciliation
    Snapshot of the firmware before implementing the last-write-wins
    convergence protocol (logical-clock MSG_STATE heartbeats) on top of
    the existing delta-based sync model.
    Claude-Session: https://claude.ai/code/session_01X2bwAhHbT4uMXDQyVnHNPd
    [config.h, linklite-bar.ino, linklite-controller.ino]
2026-08-26 kicad and temp logger
    [.step, bom.csv, designators.csv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]
